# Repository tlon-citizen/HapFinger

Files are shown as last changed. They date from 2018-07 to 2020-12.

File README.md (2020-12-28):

# HapFinger
<b>Vibrotactile Fingercap for Wireless Tabletop/3D Interaction</b>

HapFinger is a fingertip-worn wireless (Bluetooth 2.4 GHz Band) device to be used in the index finger.
A vibrating element is located right at the fingertip and is controlled by embedded software that controls the intensity according to signals received from the computer. The case encloses an RF51822 SoC (System on a Chip) based on a 32-bit ARM Cortex.
The device provides feedback with a Linear Resonant Actuator (LRA, 5mm diameter x 3mm thickness, Precision Microdrives C10-100) spinning at a resonant frequency of 200Hz while variating the intensity from level 0 to 128 and controlled by a dedicated haptic driver (TI DRV2605L) and supporting overdriving and active braking.
It is also possible to attach an IR marker and enable position tracking with external cameras and use the pressure sensure in the fingertip to design tabletop-based interaction techniques. As additional input, the device features two tactile buttons and an analog joystick wich can be easily accesed with the thumb.
The device was 3d modeled as a finger contoured electronic enclosure. The device case was 3d-printed with resin material and the total weight, including the battery, is 31 grams.

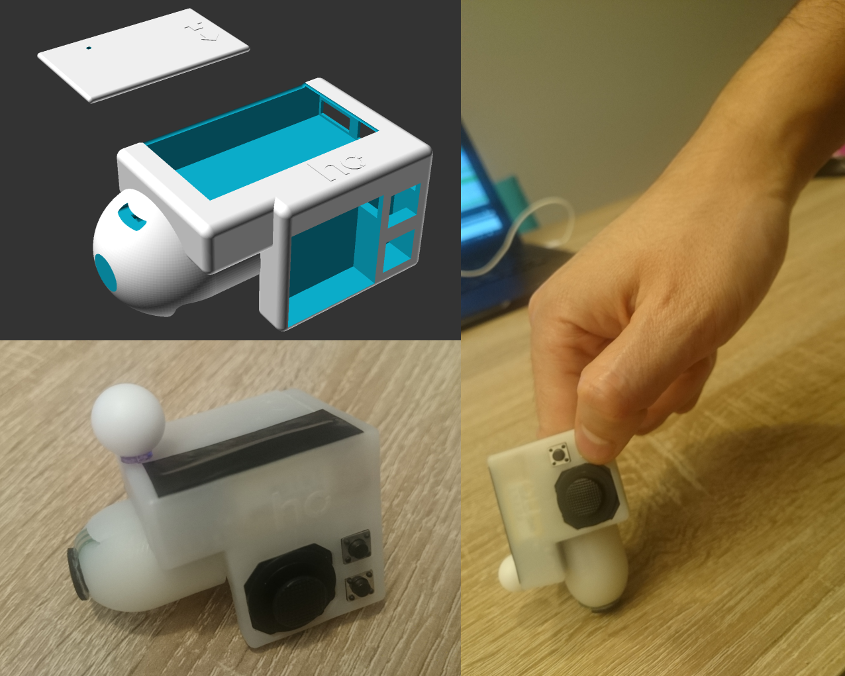
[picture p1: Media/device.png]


This repository contains all the necessary files to build a new device; model files for 3D printing, schematics for electronics, embedded software binaries, source code of a BLE server to stablish a wireless device connection from a computer and the source code of an Unity demo application featuring vibrotactile feedback in a 3D environment.

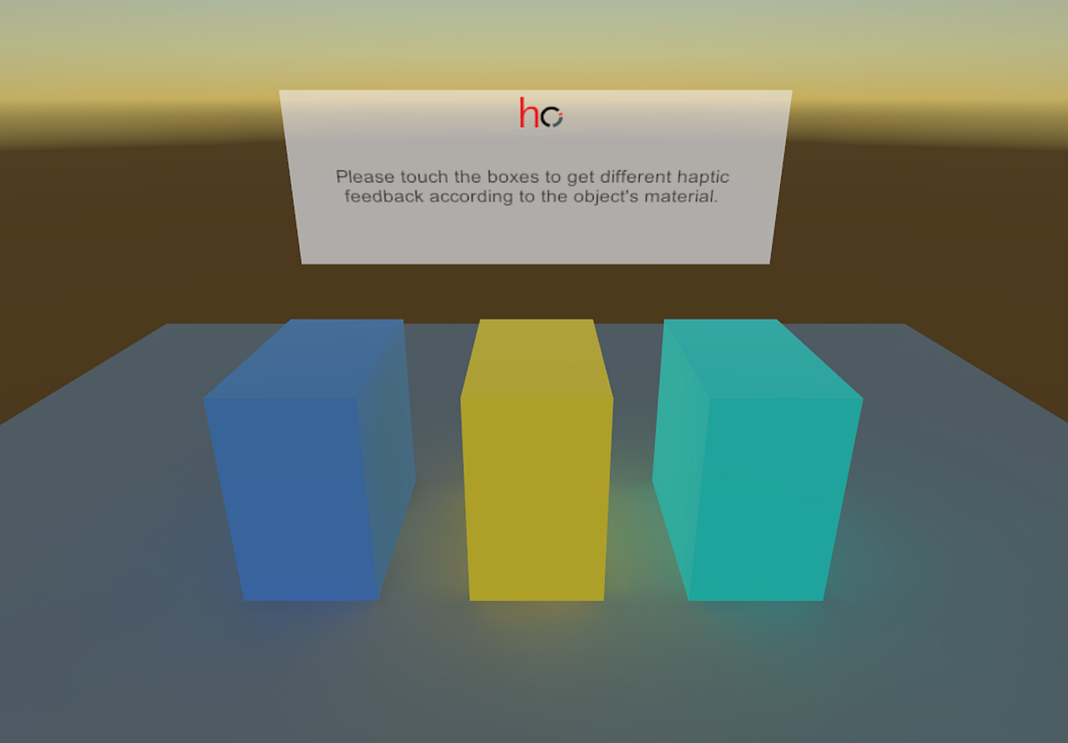
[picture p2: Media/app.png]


Analysis of Proximity-Based Multimodal Feedback for 3D Selection in Immersive Virtual Environments<br/>
Oscar Ariza, Gerd Bruder, Nicholas Katzakis, Frank Steinicke<br/>
IEEE Virtual Reality (VR)<br/>
2018

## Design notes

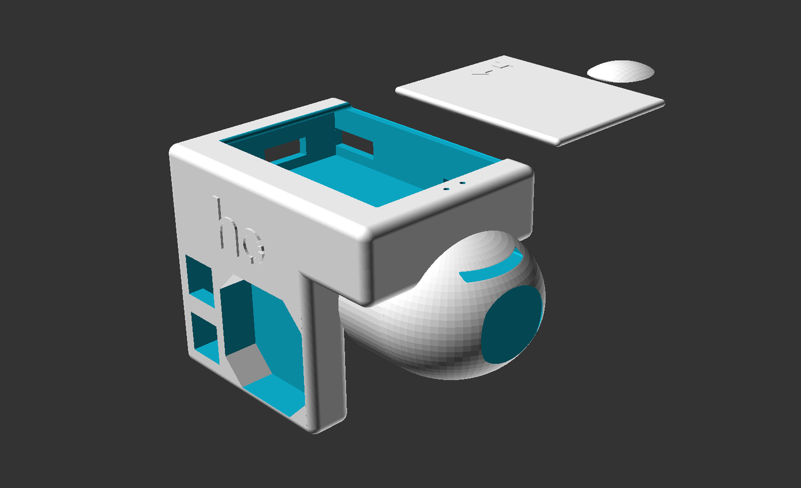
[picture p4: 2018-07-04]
3DModel/HapFingerV03.png

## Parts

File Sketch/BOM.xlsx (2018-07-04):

 | Item | URL | Quantity
A | LiPo Battery Charger | https://www.adafruit.com/product/1905 | 1
B | LiPo Battery 150 mAh 3.7V | https://www.adafruit.com/product/1317 | 1
C | IMU BNO055 (9 DOF IMU Fusion Breakout) | https://www.tindie.com/products/onehorse/bno-055-9-axis-motion-sensor-with-hardware-fusion/ | 1
D | Haptic Driver TI DRV2605L | https://www.adafruit.com/product/2305 | 1
E | LRA PM C10-100 | https://www.precisionmicrodrives.com/vibration-motors/linear-resonant-actuators-lras | 1
F | Analog thumb slider for interaction | https://www.adafruit.com/product/444 | 1
G | Resistor 10K |  | 1
H | Tactile Buttons | https://www.adafruit.com/product/367 | 2
I | Interlink FSR400 Pressure Sensor | https://eckstein-shop.de/Interlink-Drucksensor-Force-Sensing-Resistor-FSR-400-02-N-20-N-76-x-03-mmR-x-H | 1
J | BLE Nano Microcontroller | http://www.exp-tech.de/en/redbearlab-ble-nano-v2 | 1

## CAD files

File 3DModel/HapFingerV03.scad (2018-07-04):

use <Utilities.scad>;

$fn=75;

//All parameters in mm.
fingerLength    =50.0;
fingerRadius    =12.5;

module finger() {
    union()
    {
        scale([1.0, 1.03, 0.85])
        {
            rotate([0, 90, 0]) 
            {
                cylinder(h=fingerLength-fingerRadius, r=fingerRadius, center=true);
            }
            translate([(fingerLength-fingerRadius)/2, 0.0, 0.0])
            {
                sphere(r=(fingerRadius+0.01), center=true);
            }
        }
    };
}

module fingerCap() {
    difference()
    {
        color("YellowGreen",1.0)
        finger();
        
        scale([1.0, 0.9, 0.85])
            translate([-4.85, 0.0, 0.0])
                color("SteelBlue",1.0)
                finger();
        
        translate([-34.6, 0.0, -25.5]) // Finger tunnel A
            color("DarkOrange", 1.0)
            roundedCube(43.0, 25.0, 25.0, 3.0);
        
        translate([-34.6, -25.0, -31.5]) // Finger tunnel B
            color("DarkOrange", 1.0)
            roundedCube(43.0, 25.0, 25.0, 3.0);
        
        fingerTip();
    }
}

module fingerTip() {
    intersection()
    {
        color("YellowGreen",1.0)
        finger();

        translate([32.075, 0.0, 0.0]) // Tip slice for the pressure sensor
        {
            rotate([90.0, 0.0, 90.0])
            {
                color("DarkOrange",1.0)
                cylinder(h=5.0, r=6.0, center=true);
            }
        }
    }
}

module lra() {
    connectorRadio = 1.6;
    connectorDepth = 2.5;
    translate([22.5, 0.0, -1.15])
    {
        rotate([90.0, 0.0, 90.0])
        {
            color("LightSteelBlue",1.0)
            cylinder(h=6.0, r=5.5, center=true);
            
            translate([0.0, 5.80, 1.70])
            color("Yellow", 1.0)
            hull()
            {
                cube([connectorRadio*2, connectorRadio, connectorDepth], center=true);
                translate([0.0, connectorRadio, 0.0])
                cylinder(h=connectorDepth, r=connectorRadio, center=true);
            };            
        }
    };
}

module componentsBed() {
    translate([-19.6, -12.0, 7.0])
    {
        color("Orange", 1.0)
        roundedCube(40.0, 28.75, 8.0, 3.0);
    }
}

module componentsBox() {
    yPos    =12.75;
    zOffset =-10.0;
    xOffset =0.5;
    
    union()
    {
        difference()
        {
            union()
            {
                componentsBed();
                translate([-20.1+xOffset, yPos, -7.5+zOffset]) // Input Controls Box
                {
                    color("Orange", 1.0)
                    roundedCube(28.0, 4.0, 25.0, 3.0);
                };
                
                //translate([-4.5, 18.1, 7.5]) // HCI Logo
                translate([-4.5, 18.7, 7.5]) // HCI Logo
                {
                    //rotate([90, 180.0, 180,0])
                    rotate([90, 180.0, 0,0])
                    color("Green", 1.0)
                    scale([8.5, 8.5, 9.5])
                    import("hciLogo.stl", convexity=3);
                }
            }
            translate([-19.55, -12.1, 7.0]) //Interior
            {
                color("Gray", 1.0)
                cube([40.0, 29.0, 8.4]);
            }
            
            componentsLid(); // Lid Gutter
            
            translate([-10.5+xOffset, yPos, -7.5+zOffset]) // Joystick Hole
            {
                color("Gray", 1.0)
                cube([18.5, 5.5, 18.5]);
            }

            translate([-18.7+xOffset, yPos, 3.5+zOffset]) // Button A Hole
            {
                color("Gray", 1.0)
                cube([6.5, 7.5, 6.5]);
            }
            translate([-18.7+xOffset, yPos, -6.0+zOffset]) // Button B Hole
            {
                color("Gray", 1.0)
                cube([6.5, 7.5, 6.5]);
            }
            translate([-6.0, 12.75, -2.0]) // Components-Controls Hole
            {
                color("Gray", 1.0)
                cube([10.5, 3.0, 10.0]);
            }
            translate([-18.7+xOffset, 12.75, -1.5+zOffset]) // Inter-Button Channel
            {
                color("Gray", 1.0)
                cube([6.5, 3.0, 20.0]);
            }
        }
        
        joystickCorners(xOffset, yPos, zOffset);
    }
}

module joystickCorners(xOffset, yPos, zOffset)
{
    translate([-10.6+xOffset, 5.5+yPos, 7.2+zOffset]) // Joystick Corner A
    {
        rotate([90, 0.0, 0,0])
        color("Orange", 1.0)
        extrudedTriangle(5.5, 5.55); 
    }
    translate([-6.7+xOffset, 5.5+yPos, -7.6+zOffset]) // Joystick Corner B
    {
        rotate([90, -90.0, 0,0])
        color("Orange", 1.0)
        extrudedTriangle(5.5, 5.5); 
    }
    translate([8.1+xOffset, 0.0+yPos, 7.2+zOffset]) // Joystick Corner C
    {
        rotate([90, 0.0, 180,0])
        color("Orange", 1.0)
        extrudedTriangle(5.5, 5.5); 
    }
    translate([4.2+xOffset, 0.0+yPos, -7.6+zOffset]) // Joystick Corner D
    {
        rotate([90, -90.0, 180,0])
        color("Orange", 1.0)
        extrudedTriangle(5.5, 5.5); 
    }
}

module componentsLid() {
    translate([-16.45, -13.2, 15.9])
    {
        difference()
        {
            union()
            {
                color("SteelBlue", 1.0)
                roundedCube(33.4, 25.0, 0.01, 1.25);
                
                translate([3.7, 9.0, 0.55])
                {
                    color("Yellow", 1.0)
                    arrow();
                }
                translate([3.7, 5.0, 0.55])
                {
                    color("Yellow", 1.0)
                    rotate([0, 0, 180.0])
                    arrow();
                }
            }
        }
    }
}

module channels() {
    translate([20.5, -5.25, 7.25]) // Pressure sensor
    {
        color("Red", 1.0)
        roundedCube(9.0, 10.5, 0.5, 0.5);
    }

    translate([-19.54, -13.5, 8.6]) // On/Off Switch
    {
        color("Red", 1.0)
        cube([9.0, 3.0, 3.0]);
    }
    
    translate([-21.5, -6.1, 8.6]) // Mini-USB-Charger Plug
    {
        color("Red", 1.0)
        cube([3.0, 8.0, 3.0]);
    }

    translate([4.8, -13.5, 7.01]) // Serial Port
    {
        color("Red", 1.0)
        cube([15.5, 3.0, 3.0]);
    }
    
    hole(19.0, -1.5, 16.0); // IR LED Hole A
    hole(19.0,  1.5, 16.0); // IR LED Hole B
}

module fingerCapModel() {
    difference()
    {
        union()
        {
            difference()
            {
                fingerCap();
                lra();
                componentsBed();
            }
            componentsBox();
        }
        channels();
    }
    translate([0.0, -35.0, 0.0])
    {
        componentsLid();
    }
    rotate([0.0, -90.0, 0,0]) 
    {
        translate([-15.0, -60.0, 0.0])
        fingerTip();
    }
}

mirror([1,0,0])
fingerCapModel();
